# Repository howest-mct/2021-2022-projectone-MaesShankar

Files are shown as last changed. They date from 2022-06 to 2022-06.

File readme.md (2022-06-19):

# Project One - Alco-CarLock

My project this year is an alcohol lock for in the car. It is a safety for people who drink and drive to much. I'm going to let the driver blow in to the sensor and see if he drank to much. If so, the car won't start for at least 3h. You have to identify yourself with a badge to see who wants to drive and it can' be manipulated by someone else. The temperature will be measured while the driver blows, that is not necessary but I'm going to use the data to see if there is a connection between alcohol usage and the temperature. There will be a dc motor to test and show the result of my project but it is the meaning to implement it in to a car. 

If u are an extern person you can look at the Ip adress on the device, make sure you're connected to the same network and lookup the ip address in your browser.

## Sparringspartner
Kato Borms
## Inhoud
### Starting with Fritzing
I'm going to start with my fritzing scheme, I made a scheme on paper to see if I connected something wrong, now it is easier to digitalise. I wrote down the types
of my sensors and other components so I can look them up in fritzing. I am waiting for approval.
Got approval with following changes:
- Forgot pullup with DS18B20
- 2 connections got lost at mcp3008
- MQ3 component is not drawn well
- Bit cleaner

### Doing my database in the meantime
In the meantime I made a ERD scheme for my database. The tables are made, now just fill them up with dummy data. I opened an excel to list the dummy data easily and filled it in my tables. While I tried to dump my file to show it to my teachers I saw that I got an error. So I read the error and it seemed like the version of my dump.exe file was less recent then my server version so I changed the path to a newer version of the dump.exe that I downloaded online.
### Website with connection to database
I made a small boilerplate where I'm going to send my history tabel, I'm trying to make connection but there is a problem with my endpoint.
It got fixed, now I managed to get my history on the web and I got live data from my temperature sensor.

I managed to write the data to my database.

### LCD
Now I managed to show some messages on my LCD. and my IP address.

### Live data on website
I have managed to show my temperature on the site, also the history and alcohol history and users are found on the site.

### Alcohol sensor
The alcohol gas sensor, shorter, the mq-3 is a simple analoge signal. So I will read it with an MCP3008 SPI. In the picture you will fing a class that I will use in a different file, you only have to define the bus because we also have the RFID which is bus 0. So now I can call him in my main code. and simply insert read_channel("channel numbre").

Now I can save the data. I need the biggest numbre so in a for loop if 5 seconds I will check the biggest numbre and save it. That I will convert to promille.

This data i will send to the history and the alcohol history database.

### RFID
For the alcohol database I need a UserID. But that I only can determine if I have a name. So I need to scan the badge of the user.

I used a library to read my RFID. But before we can read we have to write first. So the first program I will run the riting programming and will hold the badge against the RFID. I have to insert a name. Now there is an ID and a name configured in the RFID. So if we test the reading program we will see that it will work.

Next up: connecting the RFID to the gas sensor. So before I will test for alcohol I will ask to scan the badge. If the scan is alright, I will tell the user and then He can blow. With
### 

## Instructables
https://www.instructables.com/Project-One-Alcohol-Lock/

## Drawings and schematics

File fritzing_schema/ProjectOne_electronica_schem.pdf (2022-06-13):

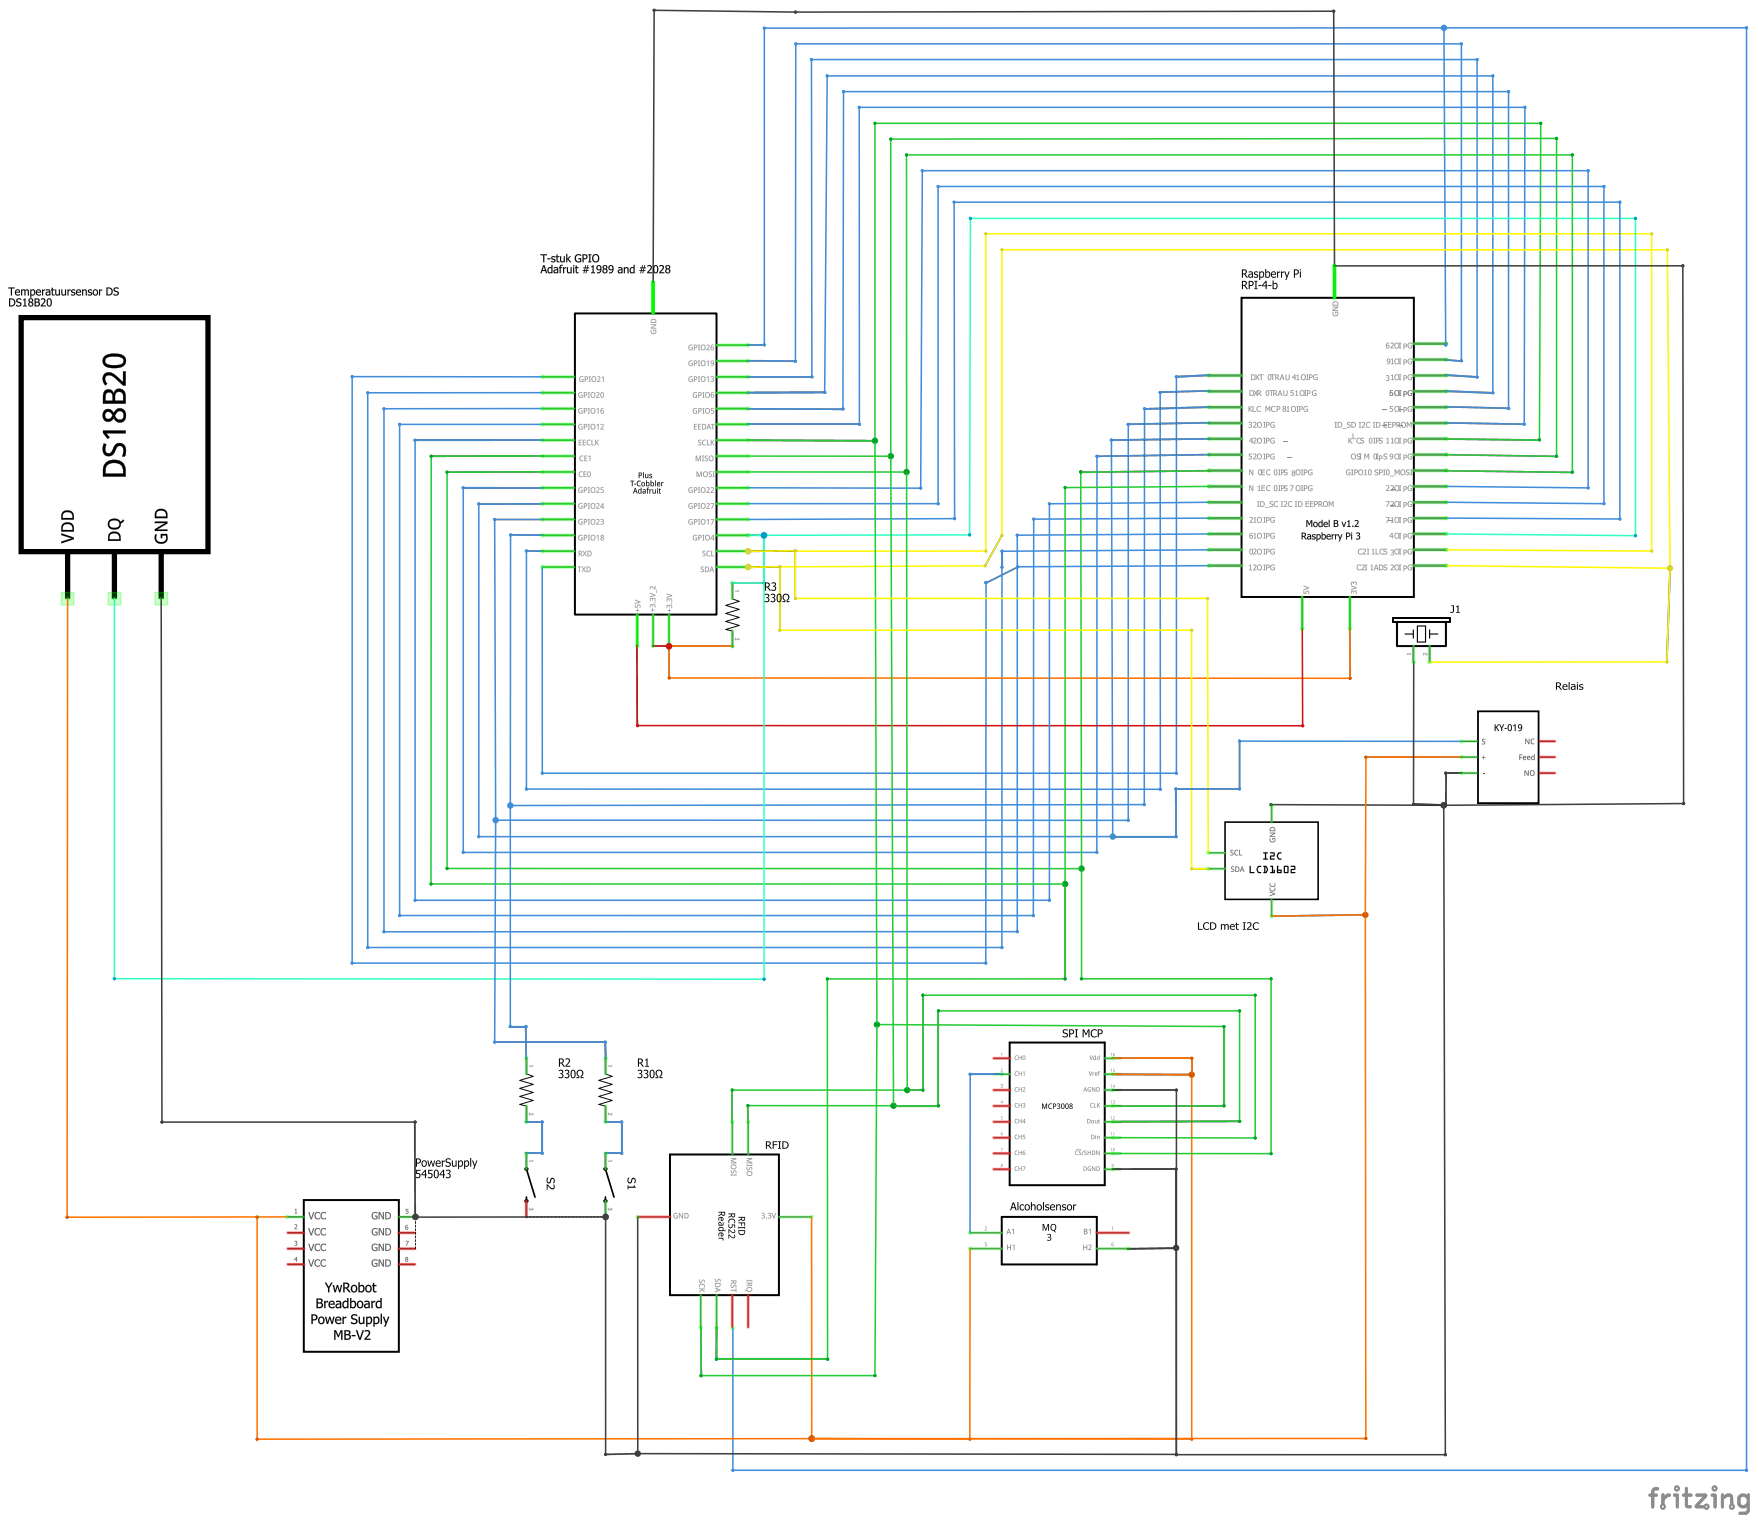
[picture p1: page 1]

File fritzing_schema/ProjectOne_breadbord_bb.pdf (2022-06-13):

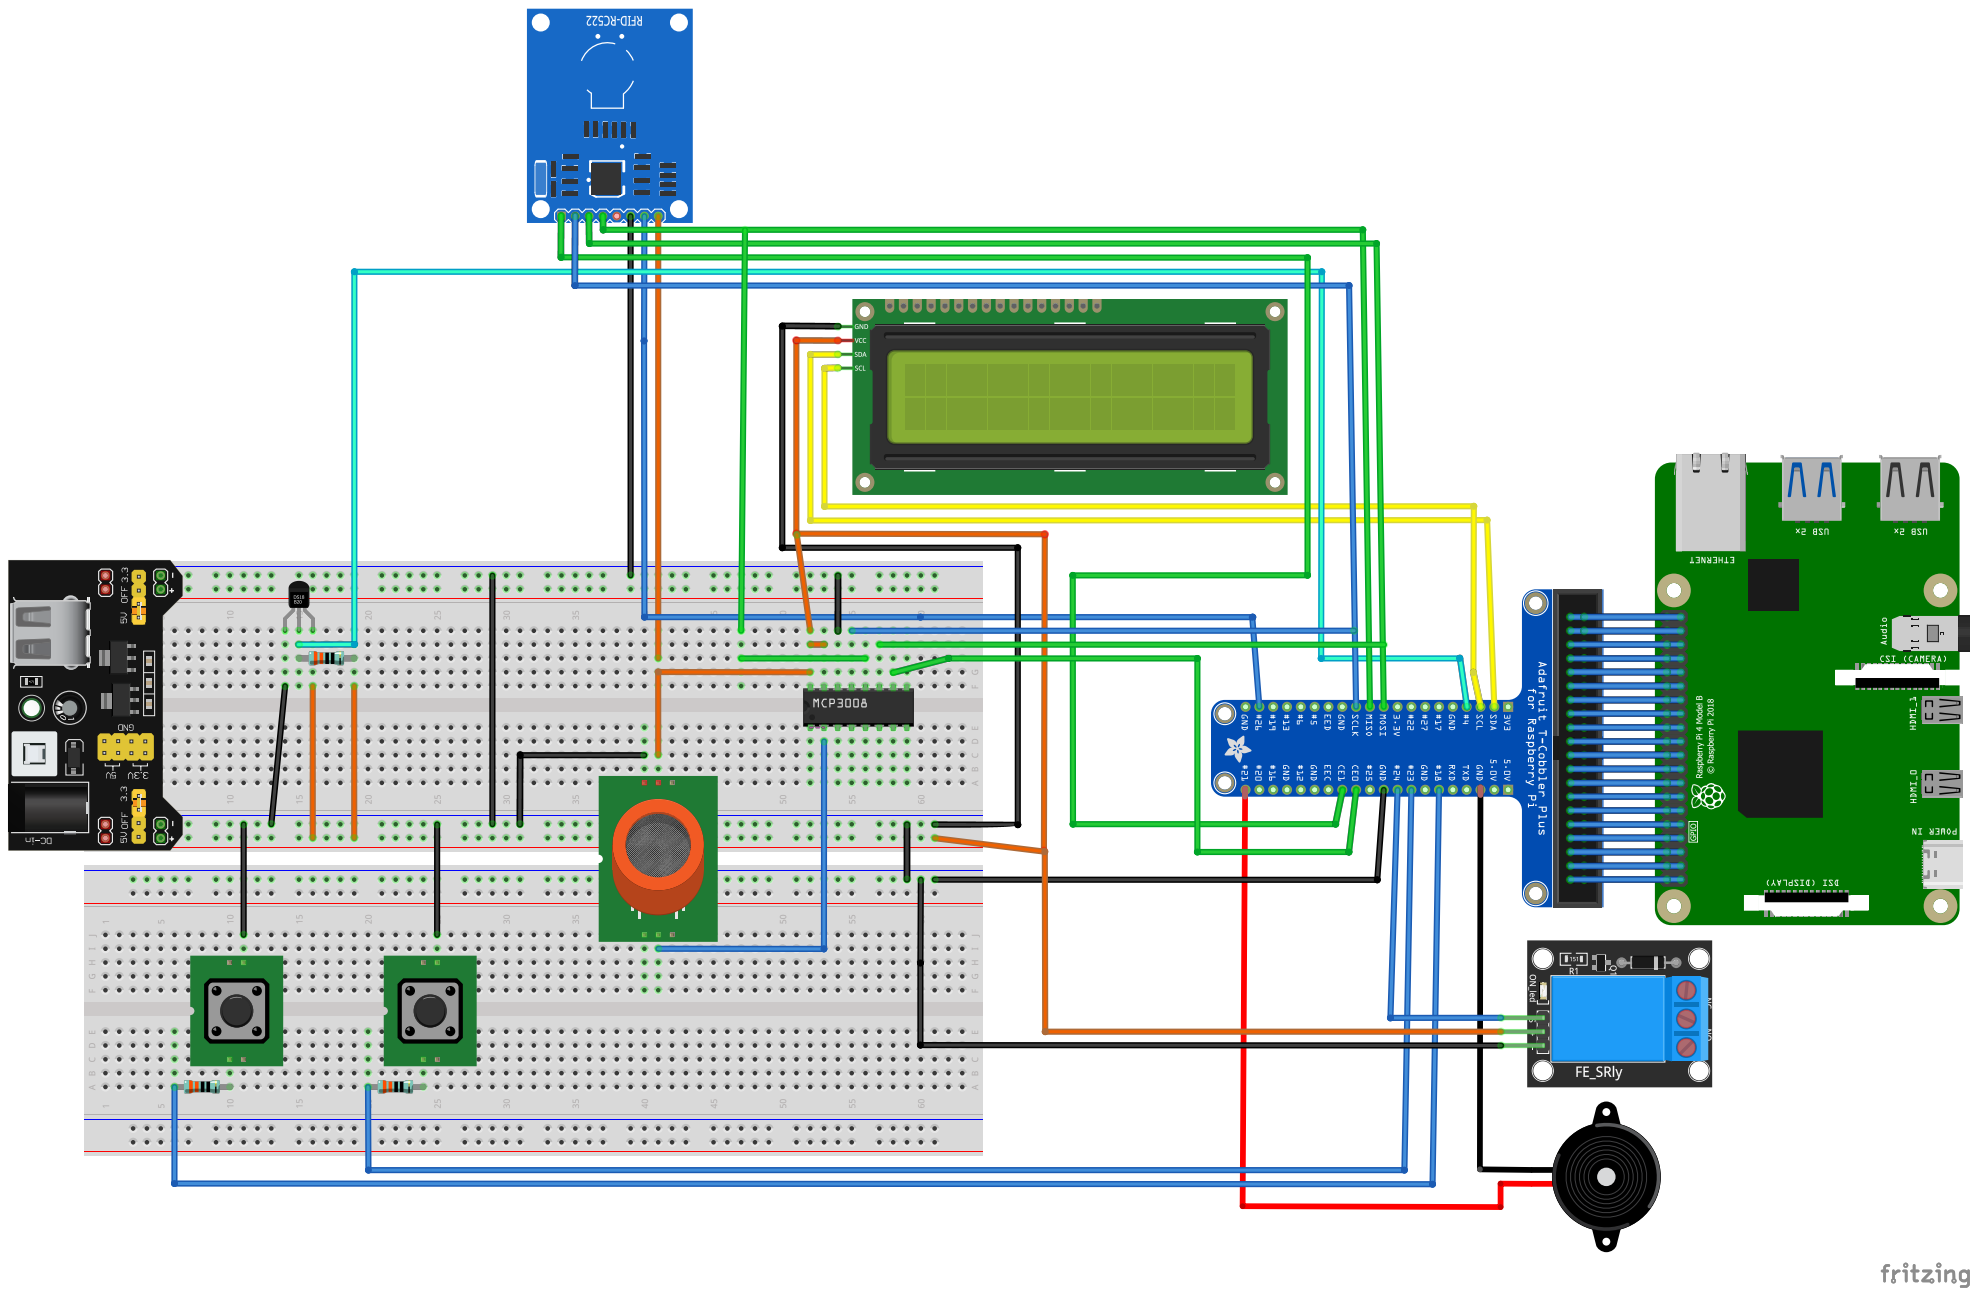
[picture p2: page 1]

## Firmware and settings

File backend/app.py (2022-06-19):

from logging import shutdown
import time
from typing import Counter
from RPi import GPIO
from helpers.klasseknop import Button
import threading
from subprocess import check_output
from flask_cors import CORS
from flask_socketio import SocketIO, emit, send
import socket
from flask import Flask, jsonify
from repositories.DataRepository import DataRepository
from selenium import webdriver
import smbus
from datetime import datetime, date
from ClassSPI import MCPclass
# from selenium import webdriver
# from selenium.webdriver.chrome.options import Options
from mfrc522 import SimpleMFRC522
import os


sensor_file_name = '/sys/bus/w1/devices/28-0183a800007d/w1_slave'
relais=24
buzzer=21
start=23
stop=18



forbidden_list=[]
dataTimer=0
temperatuur=0
alcohol=0
lock=0
startAlc=False
uitTimeS=0
uitTimeW=0
uitTimeJ=0
#LCD

I2C_ADDR  = 0x27 # I2C device address
LCD_WIDTH = 16   # Maximum characters per line

# Define some device constants
LCD_CHR = 1 # Mode - Sending data
LCD_CMD = 0 # Mode - Sending command

LCD_LINE_1 = 0x80 # LCD RAM address for the 1st line
LCD_LINE_2 = 0xC0 # LCD RAM address for the 2nd line

LCD_BACKLIGHT  = 0x08  # On 0X08 / Off 0x00

ENABLE = 0b00000100 # Enable bit

E_PULSE = 0.0005
E_DELAY = 0.0005

bus = smbus.SMBus(1) # Rev 2 Pi uses 1

counter=0

def lcd_init():
  lcd_byte(0x33,LCD_CMD) # 110011 Initialise
  lcd_byte(0x32,LCD_CMD) # 110010 Initialise
  lcd_byte(0x06,LCD_CMD) # 000110 Cursor move direction
  lcd_byte(0x0C,LCD_CMD) # 001100 Display On,Cursor Off, Blink Off
  lcd_byte(0x28,LCD_CMD) # 101000 Data length, number of lines, font size
  lcd_byte(0x01,LCD_CMD) # 000001 Clear display
  time.sleep(E_DELAY)

def lcd_byte(bits, mode):

  bits_high = mode | (bits & 0xF0) | LCD_BACKLIGHT
  bits_low = mode | ((bits<<4) & 0xF0) | LCD_BACKLIGHT

  bus.write_byte(I2C_ADDR, bits_high)
  lcd_toggle_enable(bits_high)

  bus.write_byte(I2C_ADDR, bits_low)
  lcd_toggle_enable(bits_low)

def lcd_toggle_enable(bits):
  time.sleep(E_DELAY)
  bus.write_byte(I2C_ADDR, (bits | ENABLE))
  time.sleep(E_PULSE)
  bus.write_byte(I2C_ADDR,(bits & ~ENABLE))
  time.sleep(E_DELAY)

def lcd_string(message,line):
  message = message.ljust(LCD_WIDTH," ")
  lcd_byte(line, LCD_CMD)
  for i in range(LCD_WIDTH):
    lcd_byte(ord(message[i]),LCD_CHR)

def show_ip():
    global ip
    lcd_string("",LCD_LINE_1)
    lcd_string("",LCD_LINE_2)
    time.sleep(0.3)
    lcd_string("WIFI:",LCD_LINE_1)
    lcd_string(ip,LCD_LINE_2)

# Callbacks
def callbackALC(String):
    global counter
    counter+=1
    print(counter)

    DeviceID=4
    ActieID=2
    Datum=datetime.now()
    Waarde=float(temperatuur)
    Commentaar='Temperatuursmeting'
    DataRepository.create_log(DeviceID,ActieID,Datum,Waarde,Commentaar)
    time.sleep(0.05)
    print(GPIO.input(start))
    global startAlc
    startAlc = not startAlc
    print(startAlc)
    

# Code voor Flask

app = Flask(__name__)
app.config['SECRET_KEY'] = 'geheim!'
socketio = SocketIO(app, cors_allowed_origins="*", logger=False,engineio_logger=False, ping_timeout=1)

CORS(app)


@socketio.on_error()        # Handles the default namespace
def error_handler(e):
    print(e)


# Code voor Hardware
def setup_gpio():
    GPIO.setmode(GPIO.BCM)
    GPIO.setup(relais, GPIO.OUT)
    GPIO.setup(buzzer, GPIO.OUT)
    GPIO.setup(start, GPIO.IN, pull_up_down=GPIO.PUD_UP)
    GPIO.setup(stop, GPIO.IN, pull_up_down=GPIO.PUD_UP)
    GPIO.add_event_detect(start,GPIO.FALLING,callbackALC, bouncetime=2000)
    GPIO.add_event_detect(stop,GPIO.FALLING,Shutdown, bouncetime=600)
   

def onewire():
    while True:
        global sensor_file
        sensor_file = open(sensor_file_name,'r')
        line = sensor_file.readlines()[-1]
        uitkomst = line[line.rfind("t"):]
        geheel = uitkomst[2:]
        sensor_file.close
        testuren=geheel[:2] + ',' + geheel[3:]
        data=geheel[:2] + '.' + geheel[3:]
        # print(f'onewire {testuren}')
        global temperatuur
        temperatuur=data
        # print(f"temperatuur:{data}")
        time.sleep(0.5)


def MeetAlcData():
    while True:
        klasse=MCPclass()
        data=klasse.read_channel(1)
        alcohol=round((data/1024)*3.3,2) 
        RS_gas = ((5.0 * 2000)/alcohol) - 2000
        R0 = 16000
        ratio = RS_gas/R0 # ratio = RS/R0
        x = 0.4*ratio   
        global BAC
        BAC = pow(x,-1.431)/20  #BAC in mg/L
        # print(f"alcohol:{round(BAC,2)}")
        klasse.closespi()
        time.sleep(1)

def dataTemp():
    while True:
        global temperatuur
        global dataTimer
        if dataTimer==60:
            # print("Thread")
            DeviceID=2
            ActieID=3
            Datum=datetime.now()
            Waarde=float(temperatuur)
            Commentaar='Temperatuursmeting'
            DataRepository.create_log(DeviceID,ActieID,Datum,Waarde,Commentaar)
            # return testuren
            print(Waarde)
            socketio.emit('TempData', {'temperatuur': f'{Waarde}'})
            dataTimer=0
        dataTimer+=1
        time.sleep(1)

def loop_main():
    global startAlc
    global uitTimeS
    global uitTimeW
    global uitTimeJ
    while True:
        # print('loop')
        if startAlc is True:
            MeetAlcohol()

        if uitTimeS>0:
            uitTimeS=uitTimeS-1
            # print(f's:{uitTimeS}')
            
        # time.sleep(0.5)
        if uitTimeW>0:
            uitTimeW=uitTimeW-1
            # print(f'w:{uitTimeW}')
            # time.sleep(1)

        # time.sleep(0.5)
        if uitTimeJ>0:
            uitTimeJ=uitTimeJ-1
            # print(f'JP:{uitTimeJ}')
            # time.sleep(1)


        if uitTimeS<=0 :
            uitTimeS=0
            contactor('0','933210265772')
            # time.sleep(1)

            
        if uitTimeW<=0:
            uitTimeW=0
            # print(f'{uitTimeW}:W')
            contactor('0','453047185099')
            # time.sleep(1)

        if uitTimeJ<=0:
            uitTimeJ=0
            contactor('0','648955705971')
            # time.sleep(1)

        socketio.emit('Sluiting',{'time': uitTimeW,'id':453047185099})
        time.sleep(1)
        socketio.emit('Sluiting',{'time': uitTimeS,'id':933210265772})
        time.sleep(1)
        socketio.emit('Sluiting',{'time': uitTimeJ,'id':648955705971})
        time.sleep(1)

def MeetAlcohol(idweb=0):
    global startAlc
    global uitTimeW
    global uitTimeS
    # This is for the web buttons
    if(idweb): 
        id=int(idweb)
        print(id)
    else:
        GPIO.remove_event_detect(start)
        lcd_string("",LCD_LINE_1)
        lcd_string("",LCD_LINE_2)
        time.sleep(1)
        lcd_string("Scan Badge",LCD_LINE_1)
        lcd_string("",LCD_LINE_2)
        time.sleep(3)
        id=rfid()
        setup_gpio()
    # naam='shankar'
    list_forbidden=DataRepository.read_toegang(id)
    dict_forbidden=list_forbidden[0]
    toegang=dict_forbidden['Toegang']
    print(toegang,id)
    # Is there aa timer running for the user
    control=0
    if(id==933210265772):
        control=uitTimeS
    elif(id==648955705971):
        control=uitTimeJ
    elif(id==453047185099):
        control=uitTimeW

    if control > 0:
        lcd_string("",LCD_LINE_1)
        lcd_string("",LCD_LINE_2)
        time.sleep(1)
        lcd_string("Aborting",LCD_LINE_1)
        lcd_string(f"Restricted for:{control}s",LCD_LINE_2)
        time.sleep(2)
        startAlc = False
        show_ip()
    else:
        lcd_string("",LCD_LINE_1)
        lcd_string("",LCD_LINE_2)
        time.sleep(1)
        lcd_string("Scan OK",LCD_LINE_1)
        time.sleep(3)
        lcd_string("",LCD_LINE_1)
        lcd_string("",LCD_LINE_2)
        time.sleep(1)
        lcd_string("Blow 5 seconds",LCD_LINE_1)
        lcd_string("In the sensor",LCD_LINE_2)
        
        GPIO.output(buzzer,GPIO.HIGH)
        time.sleep(0.5)
        GPIO.output(buzzer,GPIO.LOW)
        time.sleep(0.5)
        GPIO.output(buzzer,GPIO.HIGH)
        time.sleep(0.5)
        GPIO.output(buzzer,GPIO.LOW)
        time.sleep(0.5)
        GPIO.output(buzzer,GPIO.HIGH)
        time.sleep(0.5)
        GPIO.output(buzzer,GPIO.LOW)
        time.sleep(0.5)
        hoogstalcohol=0
        lcd_string("",LCD_LINE_1)
        lcd_string("",LCD_LINE_2)
        lcd_string("Keep going!",LCD_LINE_1)
        GPIO.output(buzzer,GPIO.HIGH)
        for i in range(0,6):
            global BAC
            if BAC>hoogstalcohol:
                hoogstalcohol=round(BAC,2)
            lcd_string(f"{i} s ; {hoogstalcohol}mg/l",LCD_LINE_2)
            time.sleep(1)
        GPIO.output(buzzer,GPIO.LOW)
        time.sleep(0.5)
        lcd_string("",LCD_LINE_1)
        lcd_string("",LCD_LINE_2)
        lcd_string(f"Result:",LCD_LINE_1)
        lcd_string(f"{hoogstalcohol}mg/l",LCD_LINE_2)
        time.sleep(2)
        DeviceID=1
        ActieID=3
        Datum=datetime.now()
        Waarde=float(hoogstalcohol)
        Commentaar='Alcoholmeting'
        DataRepository.create_log(DeviceID,ActieID,Datum,Waarde,Commentaar)
        list_userID=DataRepository.read_userID(id)
        # print(dict_userID)
        dict_userID=list_userID[0]
        UserID=dict_userID['UserID']
        ADatum=Datum
        AWaarde=Waarde
        DataRepository.create_alc_log(UserID,ADatum,AWaarde)
        global temperatuur
        print(f"Resultaat: {hoogstalcohol}mg/l")
        startAlc = False
        check_alcohol(hoogstalcohol,id)

def check_alcohol(percentage,id):
    if percentage >=0.30 and percentage <=0.40:      
        DataRepository.update_toegang('0',id)
        contactor('3',id)
    elif percentage>=0.40:
        DataRepository.update_toegang('0',id)
        contactor('6',id)
    else:
        DataRepository.update_toegang('1',id)
        contactor('0',id)

def contactor(tijd,id):
    global uitTimeS
    global uitTimeW
    global uitTimeJ
    # setup_gpio()
    list_forbidden=DataRepository.read_toegang(id)
    dict_forbidden=list_forbidden[0]
    toegang=dict_forbidden['Toegang']
    if str(tijd) == '3':
        if int(id)==933210265772:
            uitTimeS=120
            naam='Shankar'
        elif int(id)==453047185099:
            uitTimeW=120
            naam='Willy'
        elif int(id)==648955705971:
            uitTimeJ=120
            naam ='JP'
        
        GPIO.output(relais,GPIO.LOW)
        lcd_string(f"{naam} Blocked",LCD_LINE_1)
        lcd_string("For 3h",LCD_LINE_2)
        time.sleep(2)
        show_ip()
    elif str(tijd) == '6':
        if int(id)==933210265772:
            uitTimeS=240
            naam='Shankar'
        elif int(id)==453047185099:
            uitTimeW=240
            naam='Willy'
        elif int(id)==648955705971:
            uitTimeJ=240
            naam='JP'
        GPIO.output(relais,GPIO.LOW)
        lcd_string(f"{naam} Blocked",LCD_LINE_1)
        lcd_string("For 6h",LCD_LINE_2)
        time.sleep(2)
        show_ip()
    elif str(tijd) == '0' and toegang==1:
        lcd_string("U Can Drive",LCD_LINE_1)
        lcd_string("Travel Safe",LCD_LINE_2)
        GPIO.output(relais,GPIO.HIGH)
        time.sleep(5)
        GPIO.output(relais,GPIO.LOW)
        DataRepository.update_toegang('0',id)
        show_ip()

def rfid():
    global reader
    reader = SimpleMFRC522()
    reader.__init__()
    id, text = reader.read()
    print(id)
    print(text)
    reader.close_spi()
    DeviceID=3
    ActieID=3
    Datum=datetime.now()
    Waarde=float(temperatuur)
    Commentaar='RFID'
    DataRepository.create_log(DeviceID,ActieID,Datum,Waarde,Commentaar)
    return id

def Shutdown(String):
    DeviceID=5
    ActieID=2
    Datum=datetime.now()
    Waarde=float(temperatuur)
    Commentaar='Shutdown'
    DataRepository.create_log(DeviceID,ActieID,Datum,Waarde,Commentaar)
    lcd_string("Shutting Down",LCD_LINE_1)
    lcd_string("Goodbye!",LCD_LINE_2)
    time.sleep(2)
    lcd_string("",LCD_LINE_1)
    lcd_string("",LCD_LINE_2)
    os.system("sudo shutdown -h now")

def Shutter():
    DeviceID=5
    ActieID=2
    Datum=datetime.now()
    Waarde=float(temperatuur)
    Commentaar='Shutdown'
    DataRepository.create_log(DeviceID,ActieID,Datum,Waarde,Commentaar)
    lcd_string("Shutting Down",LCD_LINE_1)
    lcd_string("Goodbye!",LCD_LINE_2)
    time.sleep(2)
    lcd_string("",LCD_LINE_1)
    lcd_string("",LCD_LINE_2)
    os.system("sudo shutdown -h now")
def grafiekdata():
    while True:
        global dataTimer
        if dataTimer==60:
            jsontemp=DataRepository.gettemps()
            jsonalc=DataRepository.getAwaardes()
            jsondata=DataRepository.getdata()
            templist=[]
            alclist=[]
            # print(jsontemp)
            for i in range(0,8):
                templist.append(jsontemp[i]['Waarde'])
                alclist.append(jsonalc[i]['AWaarde'])
                time.sleep(0.5)
            # print(templist)
            # print(alclist)
            socketio.emit('Chart', {'temp': templist,'alc': alclist})

def alcdata():
    while True:
        global dataTimer
        if dataTimer==60:    
            result=DataRepository.getlatestalc()
            # print(result[0]['AWaarde'])
            socketio.emit('AlcoholData', {'alcohol': result[0]['AWaarde']})
        time.sleep(1)
            

# API ENDPOINTS


@app.route('/')
def hallo():
    return "Server is running, er zijn momenteel geen API endpoints beschikbaar."

@app.route('/api/v1/history/', methods=['GET'])
def read_history():
    # print('Get History')
    result = DataRepository.read_history()
    return jsonify(result)

@app.route('/api/v1/users/', methods=['GET'])
def read_users():
    # print('Get users')
    result = DataRepository.read_users()
    return jsonify(result)
@app.route('/api/v1/alchistory/', methods=['GET'])
def read_alc_historiek():
    # print('Get users')
    result = DataRepository.read_alc_history()
    return jsonify(result)

@app.route('/api/v1/alchistory/<id>/', methods=['GET'])
def read_alc_historiek_user(id):
    # print('Get users')
    result = DataRepository.read_alc_history_user(id)
    return jsonify(result)

#SocketIO
@socketio.on('connect')
def initial_connection():
    print('A new client connected')


@socketio.on('F2B_locktime')
def LockTime(time,id):
    if time=='3':
        print(f'tijd {time} id={id}')
        check_alcohol(0.35,id)
    elif time=='6':
        print(f'tijd {time} id={id}')
        check_alcohol(0.45,id)
    elif time=='0':
        print(f'tijd {time} id={id}')
        MeetAlcohol(id)
@socketio.on('F2B_shutdown')
def shutter():
        print('Shutdown')
        Shutter()


#ChromeThread
def start_chrome_kiosk():
    import os

    os.environ['DISPLAY'] = ':0.0'
    options = webdriver.ChromeOptions()
    # options.headless = True
    # options.add_argument("--window-size=1920,1080")
    options.add_argument("user-agent=Mozilla/5.0 (Windows NT 10.0; WOW64) AppleWebKit/537.36 (KHTML, like Gecko) Chrome/74.0.3729.157 Safari/537.36")
    options.add_argument('--ignore-certificate-errors')
    options.add_argument('--allow-running-insecure-content')
    options.add_argument("--disable-extensions")
    # options.add_argument("--proxy-server='direct://'")
    options.add_argument("--proxy-bypass-list=*")
    options.add_argument("--start-maximized")
    options.add_argument('--disable-gpu')
    # options.add_argument('--disable-dev-shm-usage')
    options.add_argument('--no-sandbox')
    options.add_argument('--kiosk')
    # chrome_options.add_argument('--no-sandbox')         
    # options.add_argument("disable-infobars")
    options.add_experimental_option("excludeSwitches", ["enable-automation"])
    options.add_experimental_option('useAutomationExtension', False)

    driver = webdriver.Chrome(options=options)
    driver.get("http://localhost")
    while True:
        pass


def start_chrome_thread():
    print("**** Starting CHROME ****")
    chromeThread = threading.Thread(target=start_chrome_kiosk, args=(), daemon=True)
    chromeThread.start()

def start_temp_thread():
    print("**** Starting TEMP ****")
    Thread = threading.Thread(target=onewire, args=(), daemon=True)
    Thread.start()

def start_tempData_thread():
    print("**** Starting TEMPData ****")
    ThreadData = threading.Thread(target=dataTemp, args=(), daemon=True)
    ThreadData.start()

def start_alcohol_thread():
    print("**** Starting ALC ****")
    ThreadAlc = threading.Thread(target=MeetAlcData, args=(), daemon=True)
    ThreadAlc.start()

def thread():
    print("**** Starting Loop ****")
    Threads = threading.Thread(target=loop_main, args=(), daemon=True)
    Threads.start()
def threadgrafiek():
    print("**** Starting graf ****")
    Threadgr = threading.Thread(target=grafiekdata, args=(), daemon=True)
    Threadgr.start()

def alcdatathread():
    print("**** Starting alcdata ****")
    Threadalc = threading.Thread(target=alcdata, args=(), daemon=True)
    Threadalc.start()


# ANDERE FUNCTIES


if __name__ == '__main__':
    setup_gpio()
    lcd_init()
    ip=''
    GPIO.output(relais,GPIO.LOW)
    try:
        lcd_string("Looking for IP ",LCD_LINE_1)
        lcd_string("Loading...",LCD_LINE_2)
        while len(ip)< 7 and ip[0:1] != 1:
            ipfull=str(check_output(['ip','a']))
            min=int(ipfull.find('172.30.252'))
            # min=int(ipfull.find('192.168.0.'))
            ip=str(ipfull[min:min +13])
            # print(ip)
            time.sleep(2)
        if len(ip)>7:
            lcd_string("Welcome!! ",LCD_LINE_1)
            lcd_string("Alco-CarLock",LCD_LINE_2)
            time.sleep(3)
            show_ip()
            # start_chrome_thread()
            start_temp_thread()
            start_tempData_thread()
            start_alcohol_thread()
            thread()
            threadgrafiek()
            alcdatathread()
            print("**** Starting APP ****")
            socketio.run(app, debug=False, host='0.0.0.0',port=5000)
                
    except KeyboardInterrupt:
        print ('KeyboardInterrupt exception is caught')
    finally:
        GPIO.cleanup()
